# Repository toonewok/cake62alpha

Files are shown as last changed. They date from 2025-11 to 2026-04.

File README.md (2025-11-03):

# Materials
2x RP2040-zero waveshare  
1x Left PCB  
1x Right PCB  
1x Top Left Case  
1x Bottom Left Case (100%infill)  
1x Top Right Case  
1x Bottom Right Case (100%infill)  
2x STX-3000  
62x chocv1 or mx hotswaps  
62x chocv1 or mx switches  
14x M2x6 screws
14x M2 brass inserts  
1x TRS 3.5mm cable  
1x USB C cable  
2.54mm pinheaders(male)  
2mm foam(optional)  
<br>

# Assembly
<p>Assembly is relatively self-explanatory, the only thing to call out is that you will need to solder a patch wire from pin 28 to pin 8. The yellow path on the following image will show you where that is(I do this on the bottom side of the PCB after attaching the RP2040 to the PCB) -</p>  
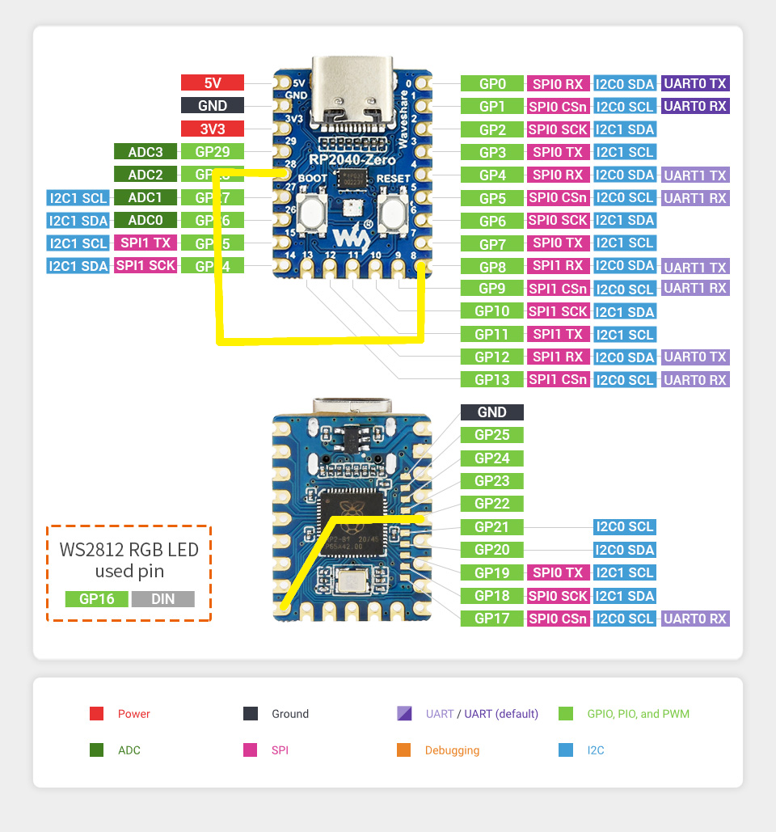
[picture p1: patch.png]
  
<br>

# Code/Firmware
<p>It needs to be stated that under no cirumstances are you to mess with the TRS jack while either half is powered, doing so could result in shorting the halves.</p> <p>Start by plugging in the halves one at a time individually, they will first appear as 'RPI-RP2' in your file browser, you will need to obtain the latest version of circuitpython for the RP2040 waveshare from the <a href="https://circuitpython.org/downloads">circuitpython downloads page.</a> Drag and drop that onto to the root of the device and it should disconnect, after a few seconds it should reappear as 'CIRCUITPY'. Now you need the most recent version of <a href="https://github.com/KMKfw/kmk_firmware/archive/refs/heads/main.zip">KMK.</a> Unzip the KMK folder and enter it, take the 'kmk' folder and drag it to the root of the RP2040. Depending on which half you are setting up take the respective code.py.X and place it on the root of the RP2040 as just 'code.py'....done:)</p>  
<br>
<p>Any keymap changes are made in the code.py, be sure to modify both halves</p>

# Default Keymap
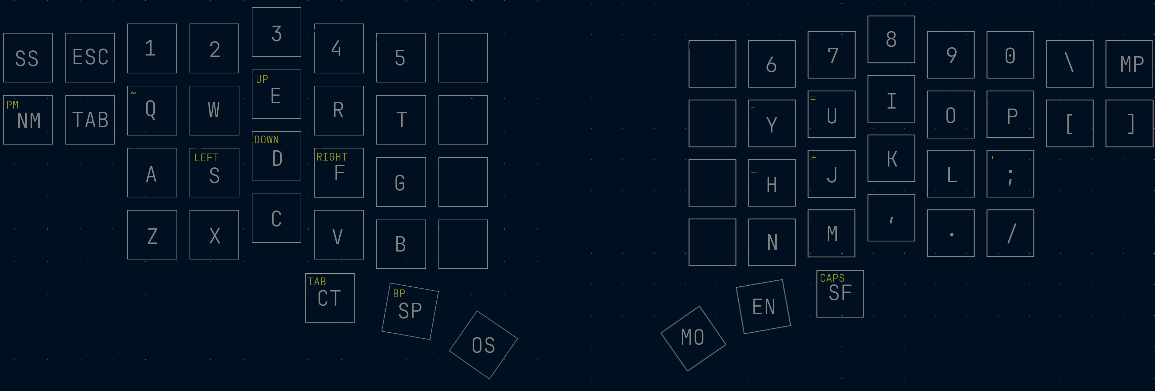
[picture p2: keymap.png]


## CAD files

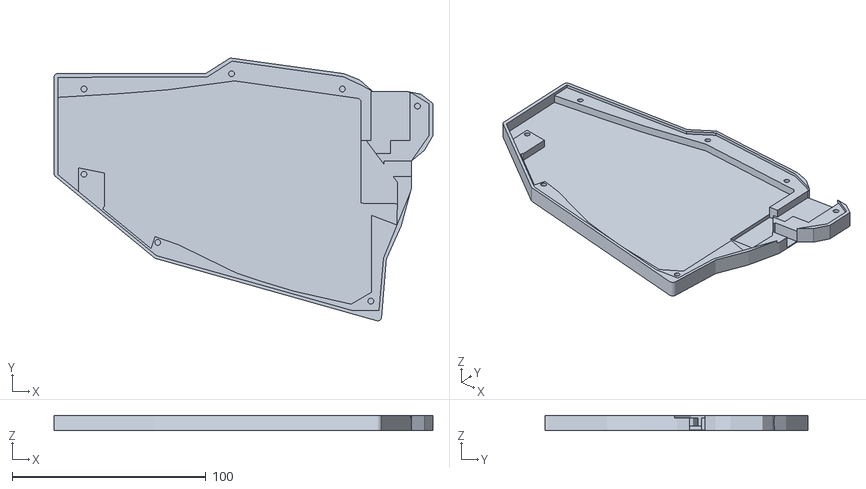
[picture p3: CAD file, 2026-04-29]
cake62-left-bottom.stl
195.6 x 135.6 x 8.00

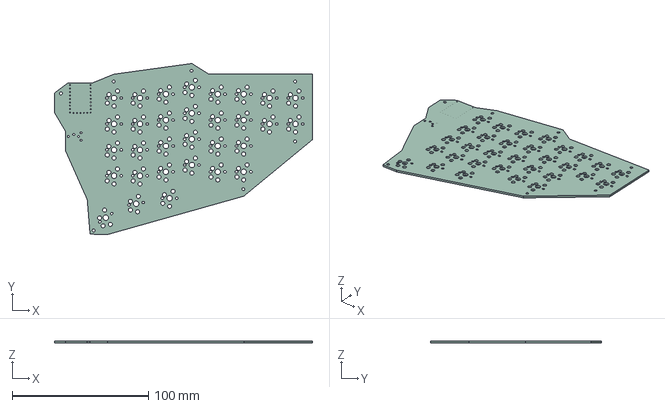
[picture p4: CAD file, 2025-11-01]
pcbfiles/cake31-right.step
189.6 x 125.7 x 1.51 mm

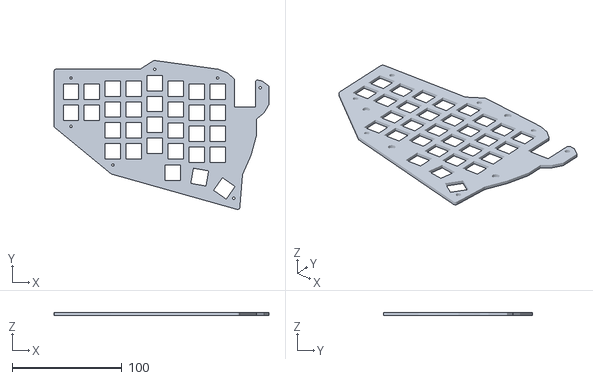
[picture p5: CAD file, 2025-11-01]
cake62-left-top.stl
195.6 x 135.6 x 2.50

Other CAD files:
pcbfiles/cake31-left.step
cake62-right-top.stl
cake62-right-bottom.stl

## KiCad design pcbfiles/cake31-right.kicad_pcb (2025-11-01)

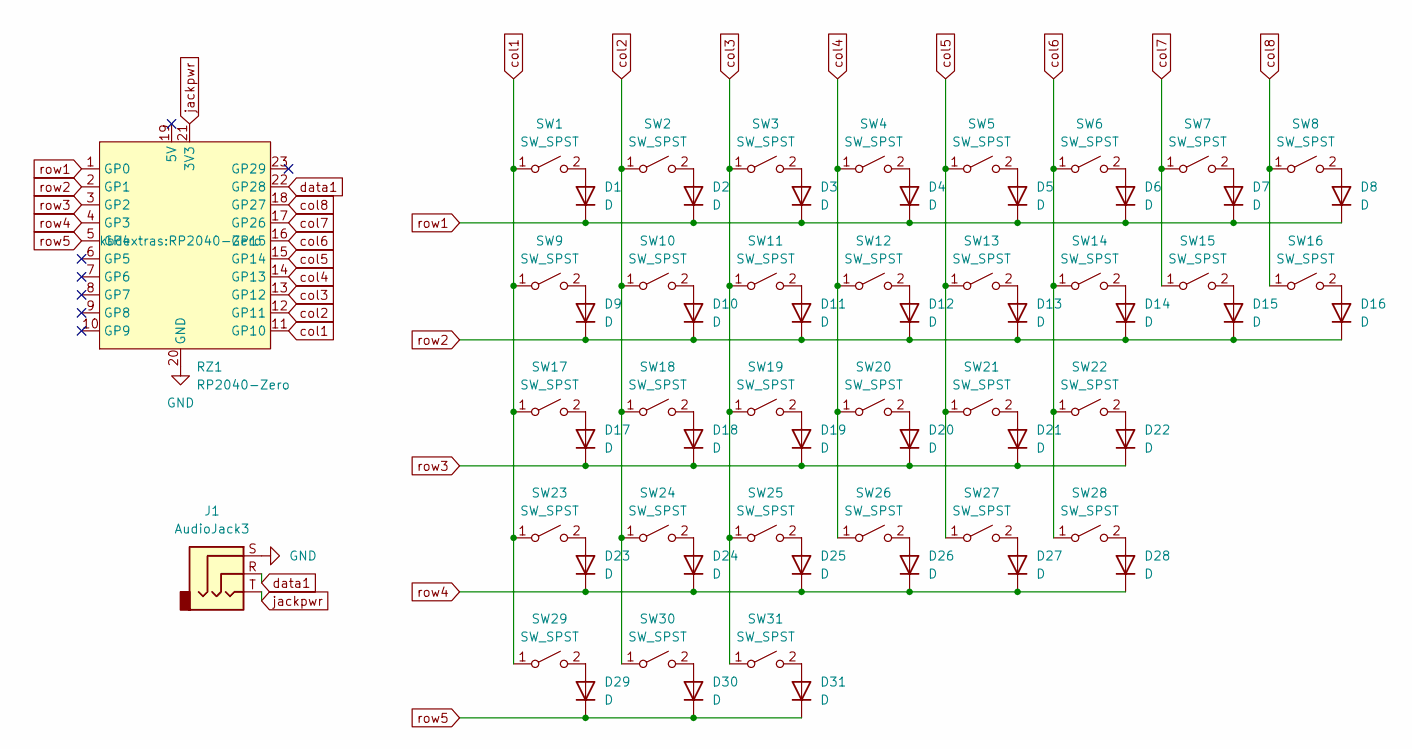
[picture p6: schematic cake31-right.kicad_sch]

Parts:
D1, D2, D3, D4, D5, D6, D7, D8, D9, D10, D11, D12, D13, D14, D15, D16, D17, D18, D19, D20, D21, D22, D23, D24, D25, D26, D27, D28, D29, D30, D31: D; 1N4148W
J1: AudioJack3; STX-3000
RZ1: RP2040-Zero
SW1, SW2, SW3, SW4, SW5, SW6, SW7, SW8, SW9, SW10, SW11, SW12, SW13, SW14, SW15, SW16, SW17, SW18, SW19, SW20, SW21, SW22, SW23, SW24, SW25, SW26, SW27, SW28, SW29, SW30, SW31: SW_SPST; mx-choc-dual

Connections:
GND: J1.S, RZ1.20 (GND)
unnamed: D1.2 (A), SW1.2 (B)
unnamed: D2.2 (A), SW2.2 (B)
unnamed: D3.2 (A), SW3.2 (B)
unnamed: D4.2 (A), SW4.2 (B)
unnamed: D5.2 (A), SW5.2 (B)
unnamed: D6.2 (A), SW6.2 (B)
unnamed: D7.2 (A), SW7.2 (B)
unnamed: D8.2 (A), SW8.2 (B)
unnamed: D9.2 (A), SW9.2 (B)
unnamed: D10.2 (A), SW10.2 (B)
unnamed: D11.2 (A), SW11.2 (B)
unnamed: D12.2 (A), SW12.2 (B)
unnamed: D13.2 (A), SW13.2 (B)
unnamed: D14.2 (A), SW14.2 (B)
unnamed: D15.2 (A), SW15.2 (B)
unnamed: D16.2 (A), SW16.2 (B)
unnamed: D17.2 (A), SW17.2 (B)
unnamed: D18.2 (A), SW18.2 (B)
unnamed: D19.2 (A), SW19.2 (B)
unnamed: D20.2 (A), SW20.2 (B)
unnamed: D21.2 (A), SW21.2 (B)
unnamed: D22.2 (A), SW22.2 (B)
unnamed: D23.2 (A), SW23.2 (B)
unnamed: D24.2 (A), SW24.2 (B)
unnamed: D25.2 (A), SW25.2 (B)
unnamed: D26.2 (A), SW26.2 (B)
unnamed: D27.2 (A), SW27.2 (B)
unnamed: D28.2 (A), SW28.2 (B)
unnamed: D29.2 (A), SW29.2 (B)
unnamed: D30.2 (A), SW30.2 (B)
unnamed: D31.2 (A), SW31.2 (B)
col1: RZ1.11 (GP10), SW1.1 (A), SW9.1 (A), SW17.1 (A), SW23.1 (A), SW29.1 (A)
col2: RZ1.12 (GP11), SW2.1 (A), SW10.1 (A), SW18.1 (A), SW24.1 (A), SW30.1 (A)
col3: RZ1.13 (GP12), SW3.1 (A), SW11.1 (A), SW19.1 (A), SW25.1 (A), SW31.1 (A)
col4: RZ1.14 (GP13), SW4.1 (A), SW12.1 (A), SW20.1 (A), SW26.1 (A)
col5: RZ1.15 (GP14), SW5.1 (A), SW13.1 (A), SW21.1 (A), SW27.1 (A)
col6: RZ1.16 (GP15), SW6.1 (A), SW14.1 (A), SW22.1 (A), SW28.1 (A)
col7: RZ1.17 (GP26), SW7.1 (A), SW15.1 (A)
col8: RZ1.18 (GP27), SW8.1 (A), SW16.1 (A)
data1: J1.R, RZ1.22 (GP28)
jackpwr: J1.T, RZ1.21 (3V3)
row1: D1.1 (K), D2.1 (K), D3.1 (K), D4.1 (K), D5.1 (K), D6.1 (K), D7.1 (K), D8.1 (K), RZ1.1 (GP0)
row2: D9.1 (K), D10.1 (K), D11.1 (K), D12.1 (K), D13.1 (K), D14.1 (K), D15.1 (K), D16.1 (K), RZ1.2 (GP1)
row3: D17.1 (K), D18.1 (K), D19.1 (K), D20.1 (K), D21.1 (K), D22.1 (K), RZ1.3 (GP2)
row4: D23.1 (K), D24.1 (K), D25.1 (K), D26.1 (K), D27.1 (K), D28.1 (K), RZ1.4 (GP3)
row5: D29.1 (K), D30.1 (K), D31.1 (K), RZ1.5 (GP4)

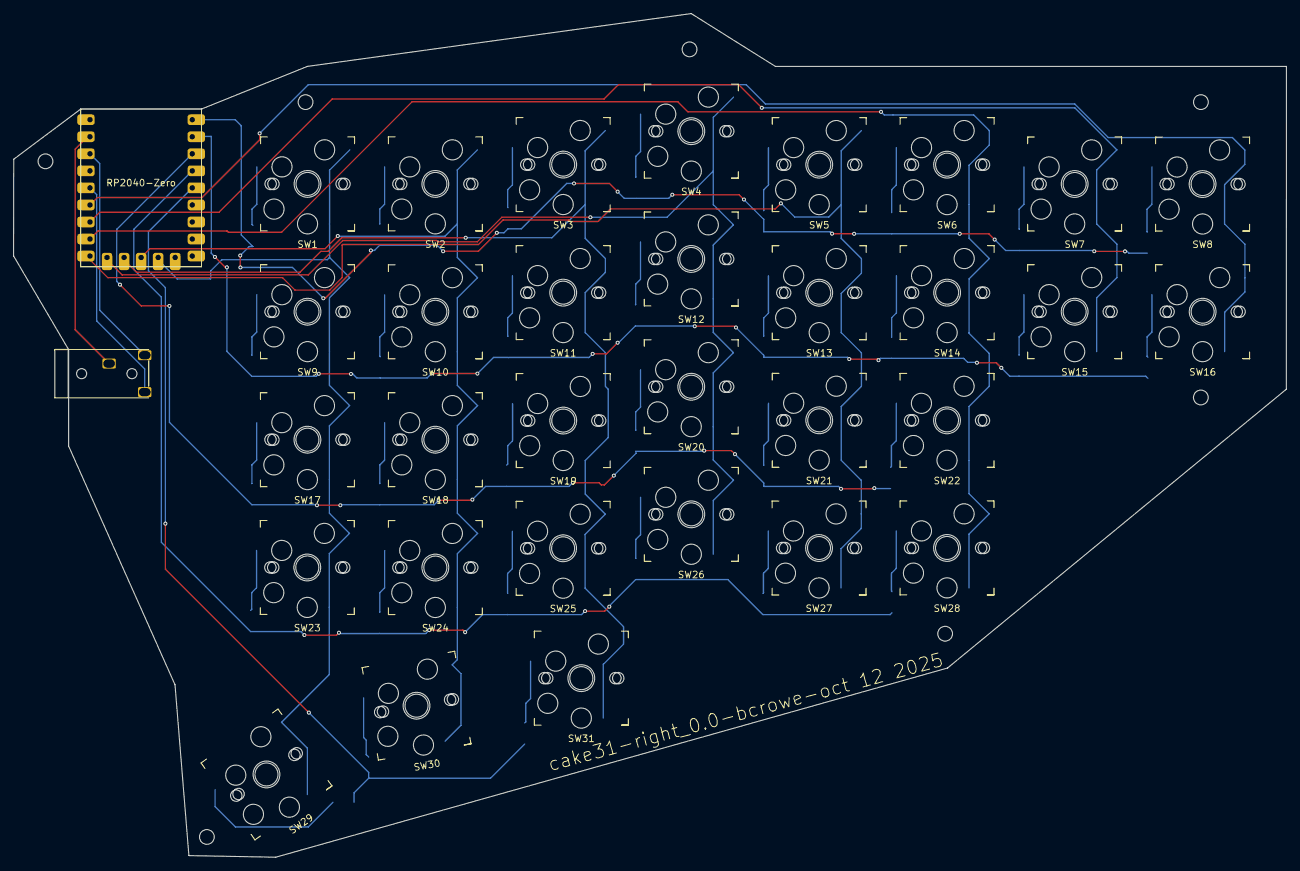
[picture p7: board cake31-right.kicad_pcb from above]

Board: 2 copper layers, 189.6 x 125.7 mm, 64 parts (0 on the bottom side), 47 nets.

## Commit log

2025-11-01 specified male pin headers
2026-04-29 stl update, hi emma
    [cake62-left-bottom.stl]
